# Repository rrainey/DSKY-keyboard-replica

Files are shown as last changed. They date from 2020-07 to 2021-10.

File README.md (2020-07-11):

# DSKY Keyboard Replica

## *This project is a work in progress -- reuse at your own risk*

This is a scale functional replica of the keyboard for the Apollo Guidance Computer. It is implemented
using modern components. The hardware in this project is
designed to be part of a larger replica of the Display and Keyboard (DSKY) module of the AGC.

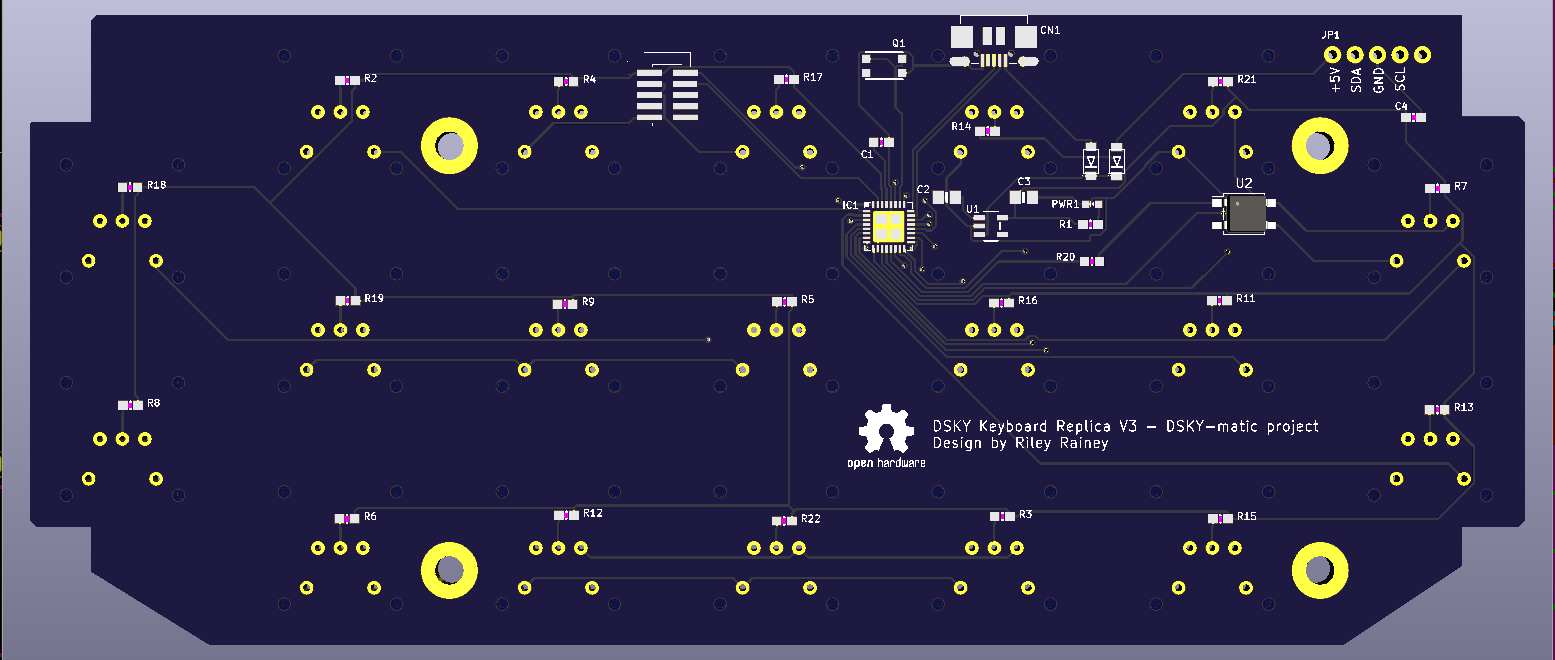
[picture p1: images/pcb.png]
See through view


This keyboard is capable of communicating to a controlling computer (a Raspberry Pi 3 or 4 in my case) via either
a USB or I2C communications interface. The board is controlled by a ATSAMD21 processor. The LP11OA1TBSRG key switches include
green backlighting LEDs, which are controlled by the ATSAMD processor.

This project is composed of these component subfolders:

* pcb - KiCad project for the controller PCB design

* firmware - circuitpython board definition and python-based test and controller firmware

* hardware - 3D-printable frame components designed using Fusion 360. STEP and Fusion source files available. Hardware models used in thie replica were derived from models found in the [AGC Mechanical CAD project](https://github.com/rrainey/agc-mechanical-cad).

## Interfaces

* USB 2.0 Micro-B port
* I2C connection via header pins
* J-LINK-compatible JTAG debugging interface (10-pin header)

## Power Requirements

* +5VDC @ 400ma from either the Micro-B USB connector or a separate +5V header pin

## Credits and Related Projects

This project is inspired by work by Ben Krasnow creating a DSKY Electroluminescent Panel replica. You'll
find information about that project in [this Applied Science video](https://www.youtube.com/watch?v=Z2o_Sp2-aBo) by Ben. Like Ben's E/L display, this project is driven by an AT SAMD21 microcontroller chip; the same chip is used in the multiple Adafruit microcontroller boards, including the Adafruit Trinket M0.

## DSKY Keyboard Replica License

Creative Commons Attribution/Share-Alike, all text above must be included in any redistribution. See license.txt for additional details.

## Adafruit Trinket M0 License

This project includes hardware design elements from the Adafruit [Trinket M0 PCB project](https://github.com/adafruit/Adafruit-Trinket-M0-PCB). Adafruit invests time and resources providing this open source design, please support Adafruit and open-source hardware by purchasing products from [Adafruit](https://www.adafruit.com)!

The Trinket M0 was designed by Limor Fried/Ladyada for Adafruit Industries.

Creative Commons Attribution/Share-Alike, all text above must be included in any redistribution. See license.txt for additional details.

## My Background

My name is Riley Rainey. I'm a software developer by profession. I spent a number of years building aerospace simulations as my day job.

## Getting Support

There's no official support available, but you can [leave comments or create an issue](https://github.com/rrainey/DSKY-keyboard-replica/issues) in this GitHub project.

  
This work is licensed under a [Creative Commons Attribution-ShareAlike 4.0 International License](http://creativecommons.org/licenses/by-sa/4.0/).

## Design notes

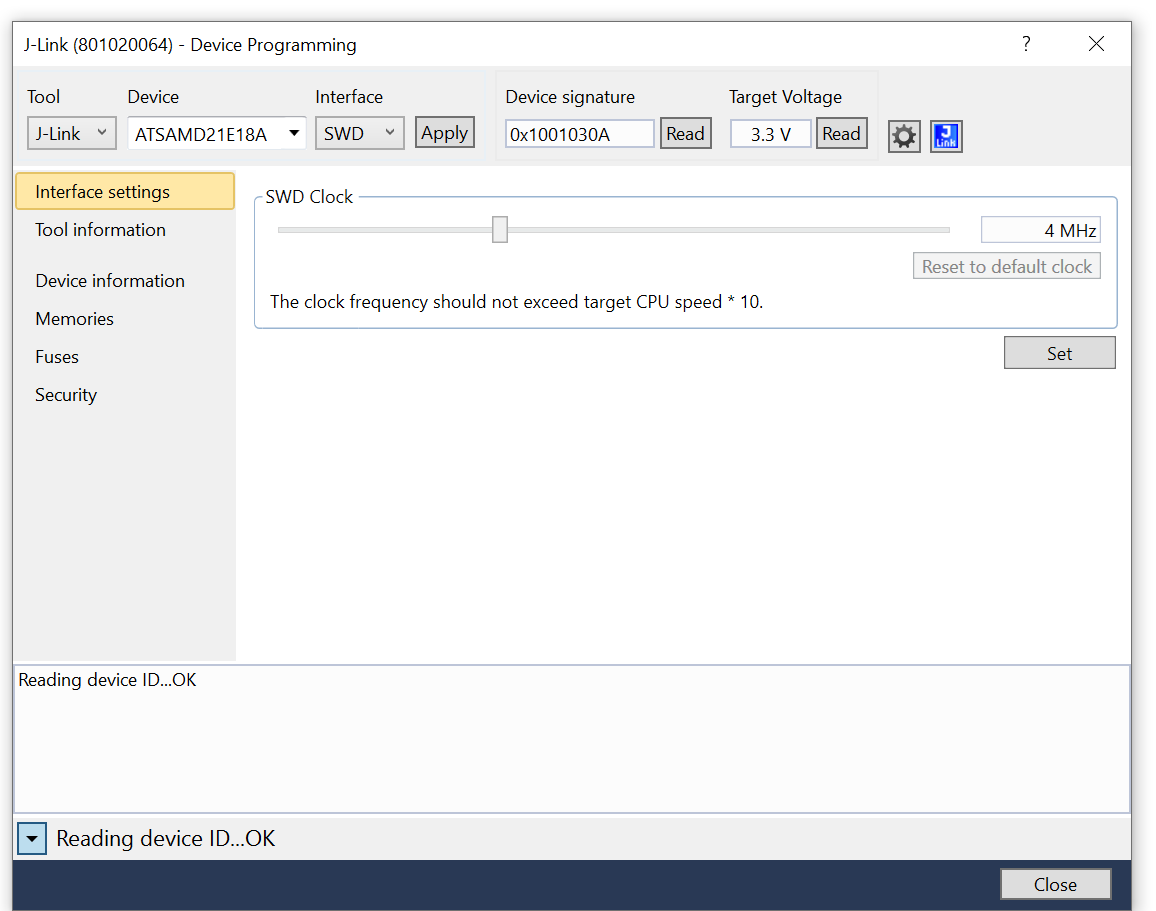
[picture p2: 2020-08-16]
images/keyboard-prog-01.PNG

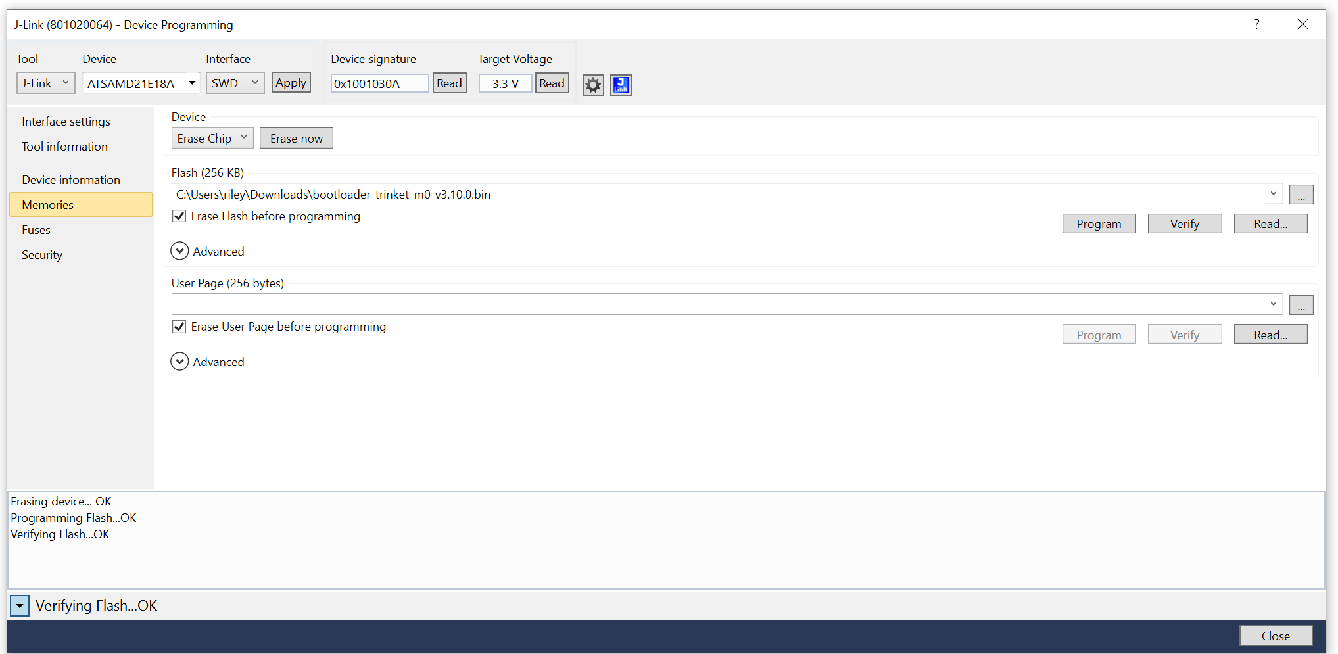
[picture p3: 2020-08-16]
images/keyboard-prog-02.PNG

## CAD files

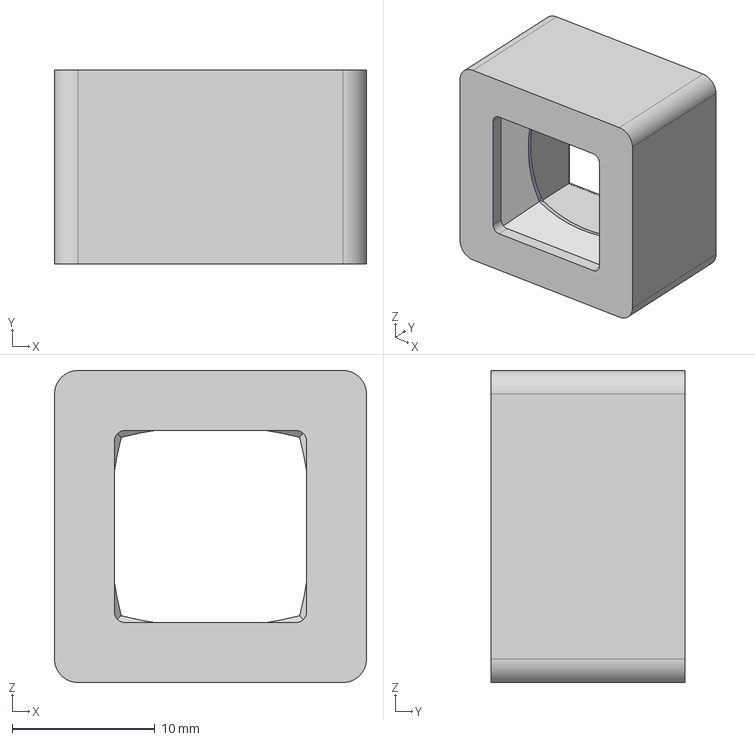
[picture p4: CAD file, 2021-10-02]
hardware/Keycap-base.step
21.8 x 13.6 x 21.8 mm

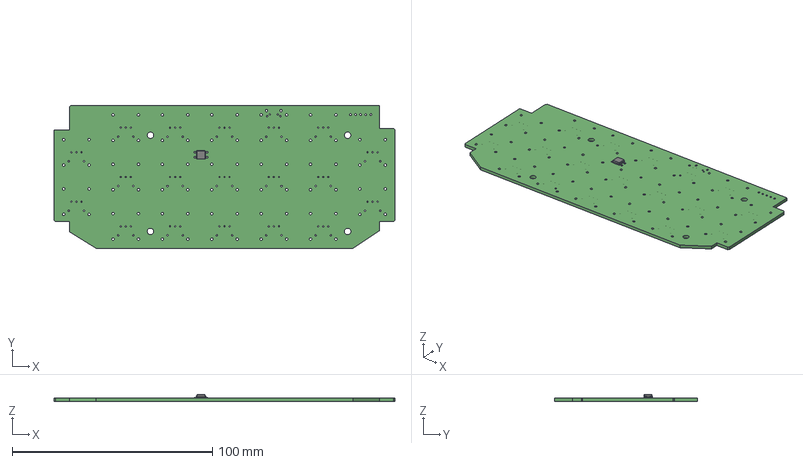
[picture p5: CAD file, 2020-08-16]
pcb/DSKY_keyboard.step
170.2 x 71.1 x 3.25 mm

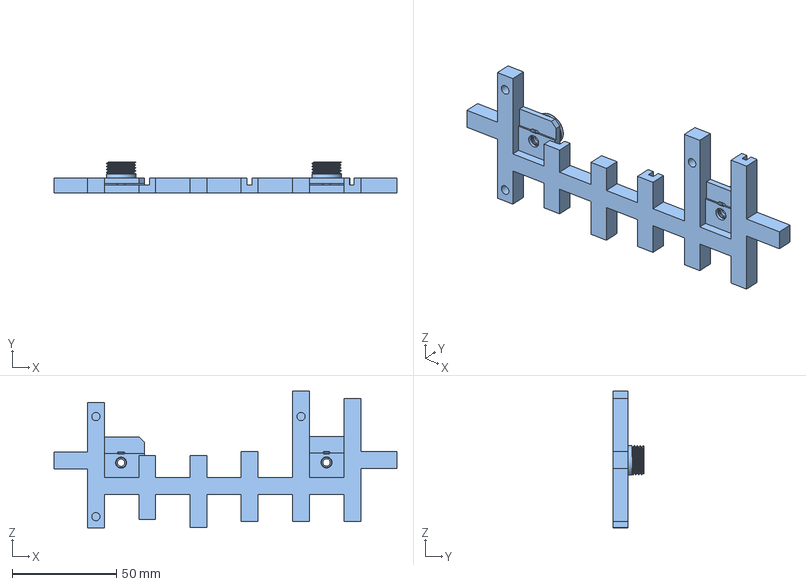
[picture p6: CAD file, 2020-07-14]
hardware/Keyboard PCB Frame.step
164.5 x 14.7 x 65.6 mm

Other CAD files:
hardware/Keyboard PCB Frame.stl
hardware/Keycap-base.stl

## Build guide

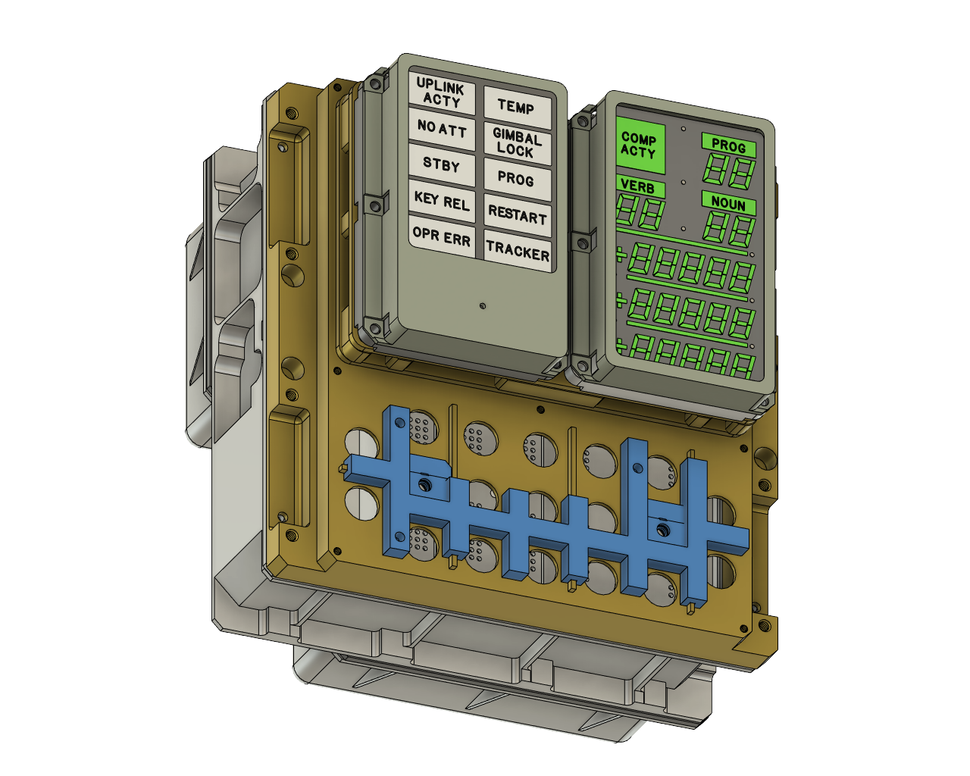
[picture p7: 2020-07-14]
images/ASSEMBLED-PCB-FRAME-02.png

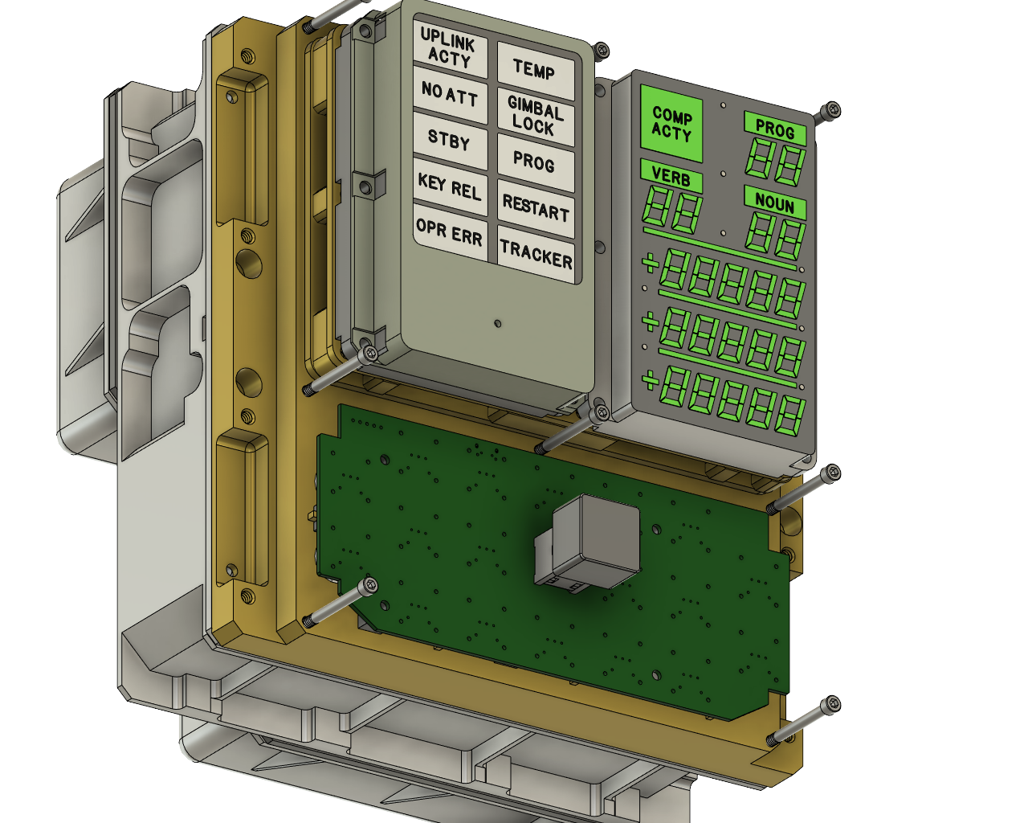
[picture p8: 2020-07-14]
images/ASSEMBLED-PCB-01.png

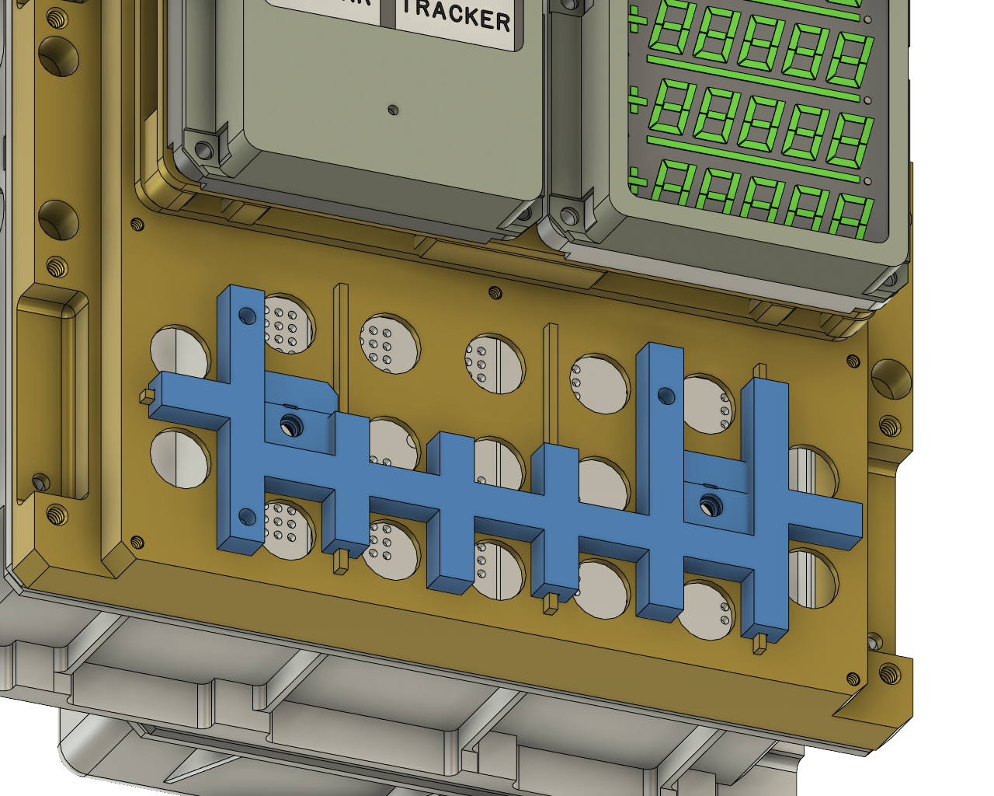
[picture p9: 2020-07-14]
images/ASSEMBLED=PCB-FRAME-01.png

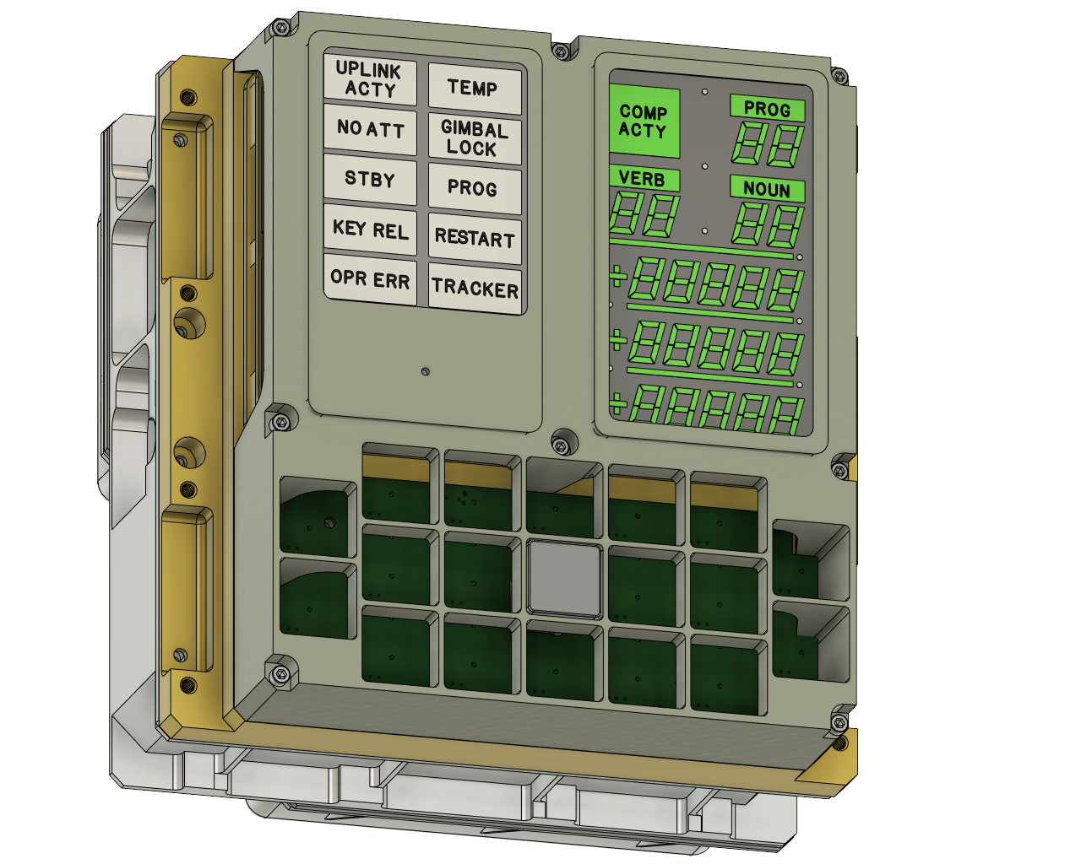
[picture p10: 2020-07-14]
images/ASSEMBLED-PCB-02.png

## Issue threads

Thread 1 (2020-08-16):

PA18 connected to two buttons

rrainey, 2020-08-16:
PA18 is connected to both the (2) and (CLR) buttons.

rrainey, 2020-08-16:
V3 PCB addresses this issue.

Closed 2020-08-16.

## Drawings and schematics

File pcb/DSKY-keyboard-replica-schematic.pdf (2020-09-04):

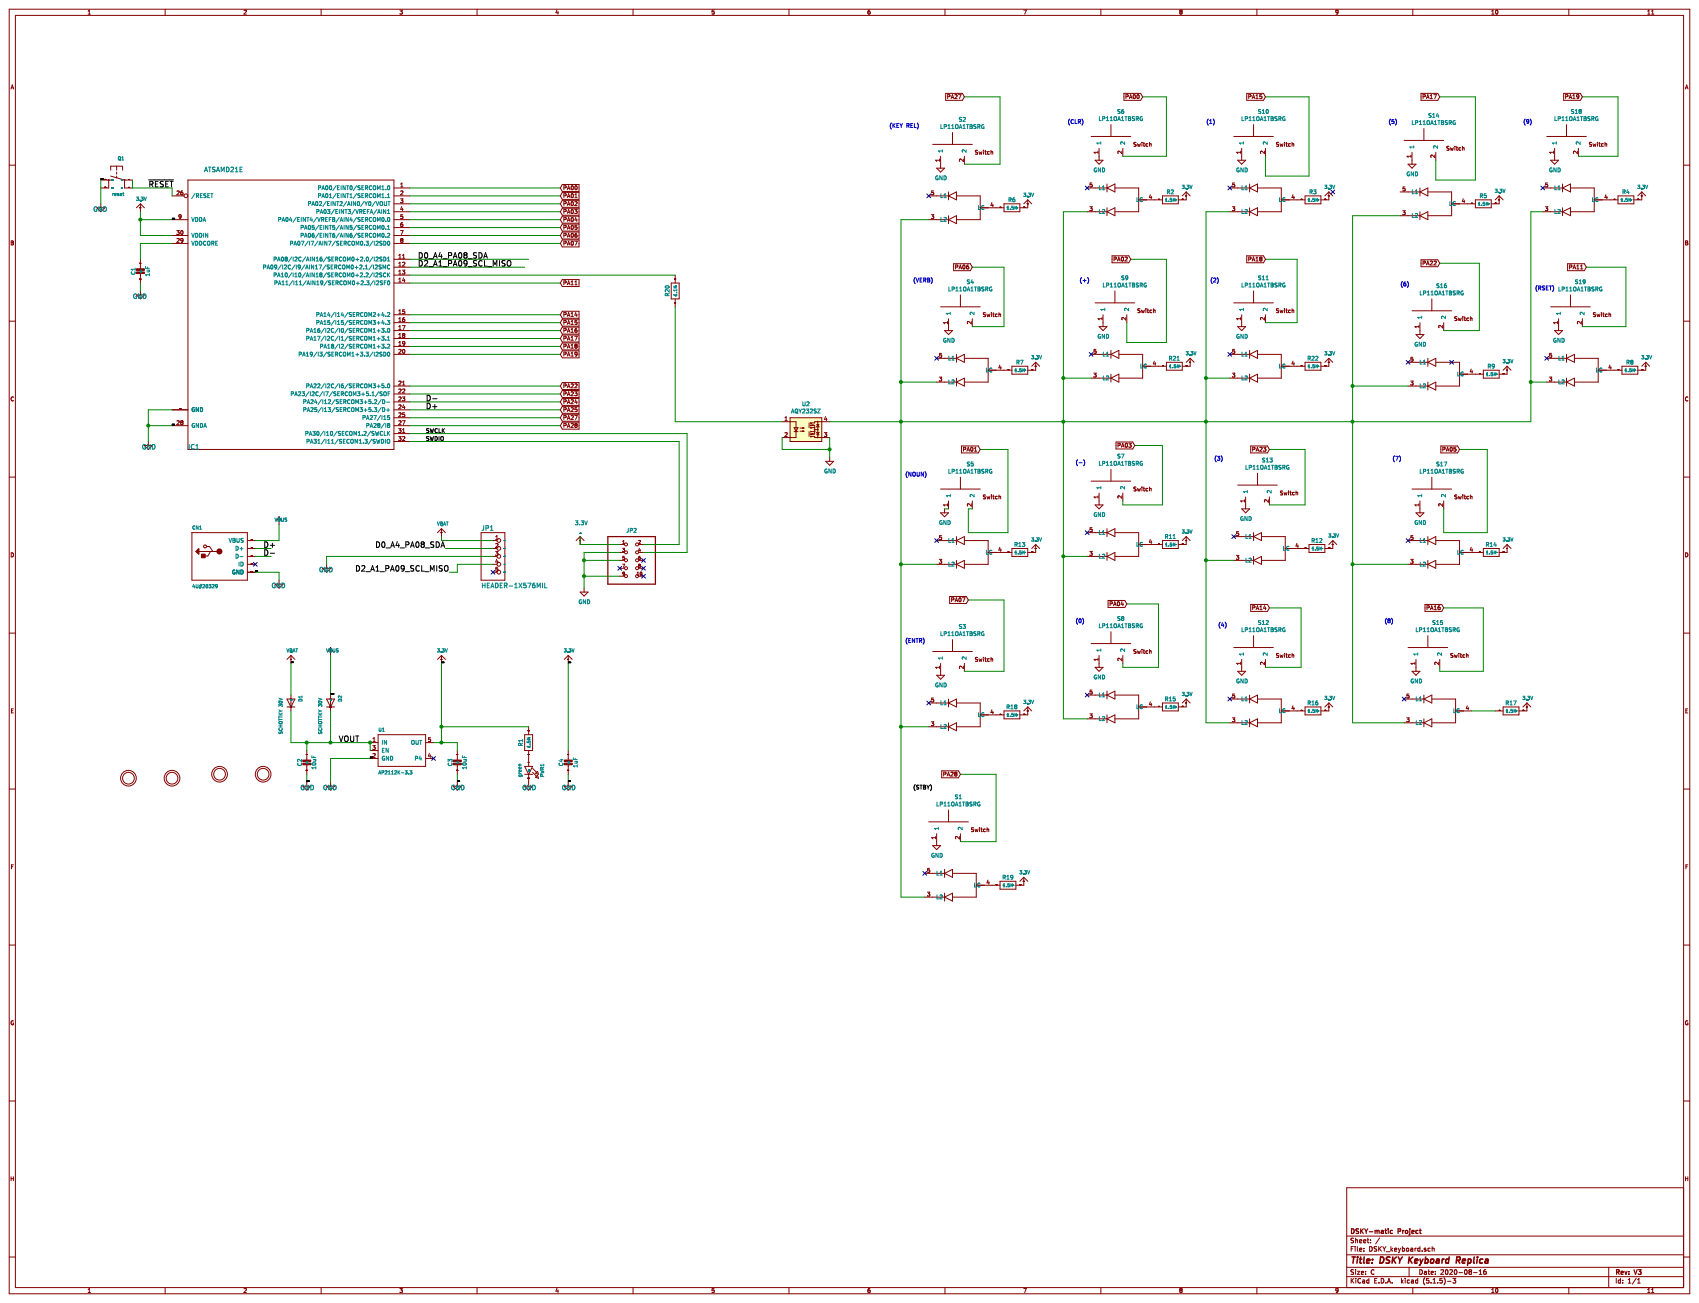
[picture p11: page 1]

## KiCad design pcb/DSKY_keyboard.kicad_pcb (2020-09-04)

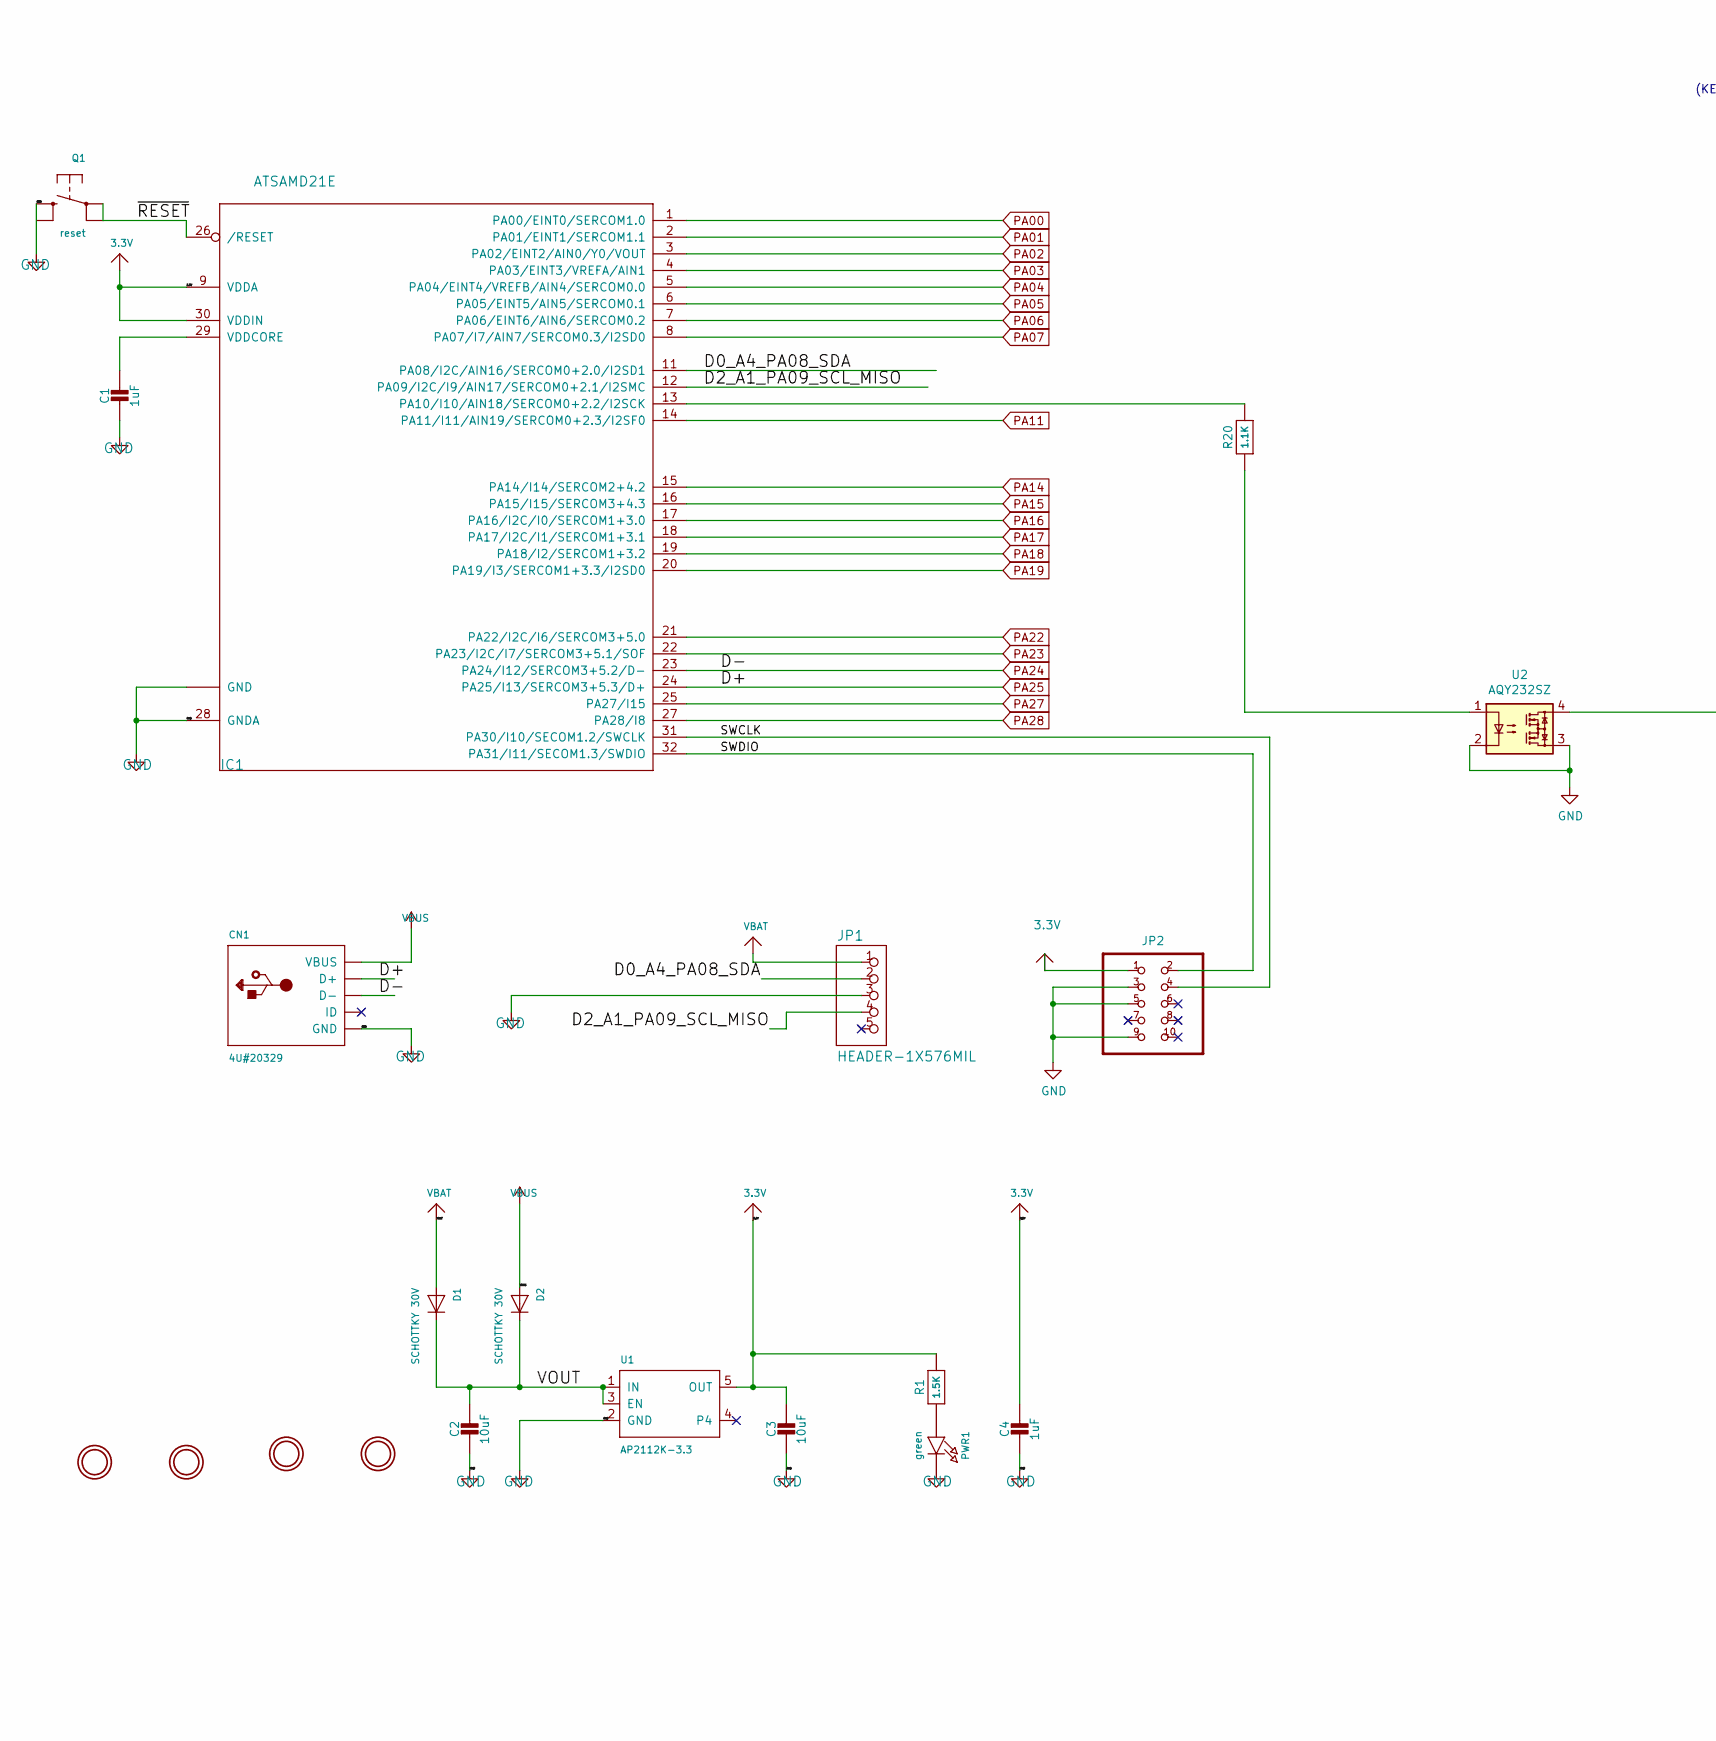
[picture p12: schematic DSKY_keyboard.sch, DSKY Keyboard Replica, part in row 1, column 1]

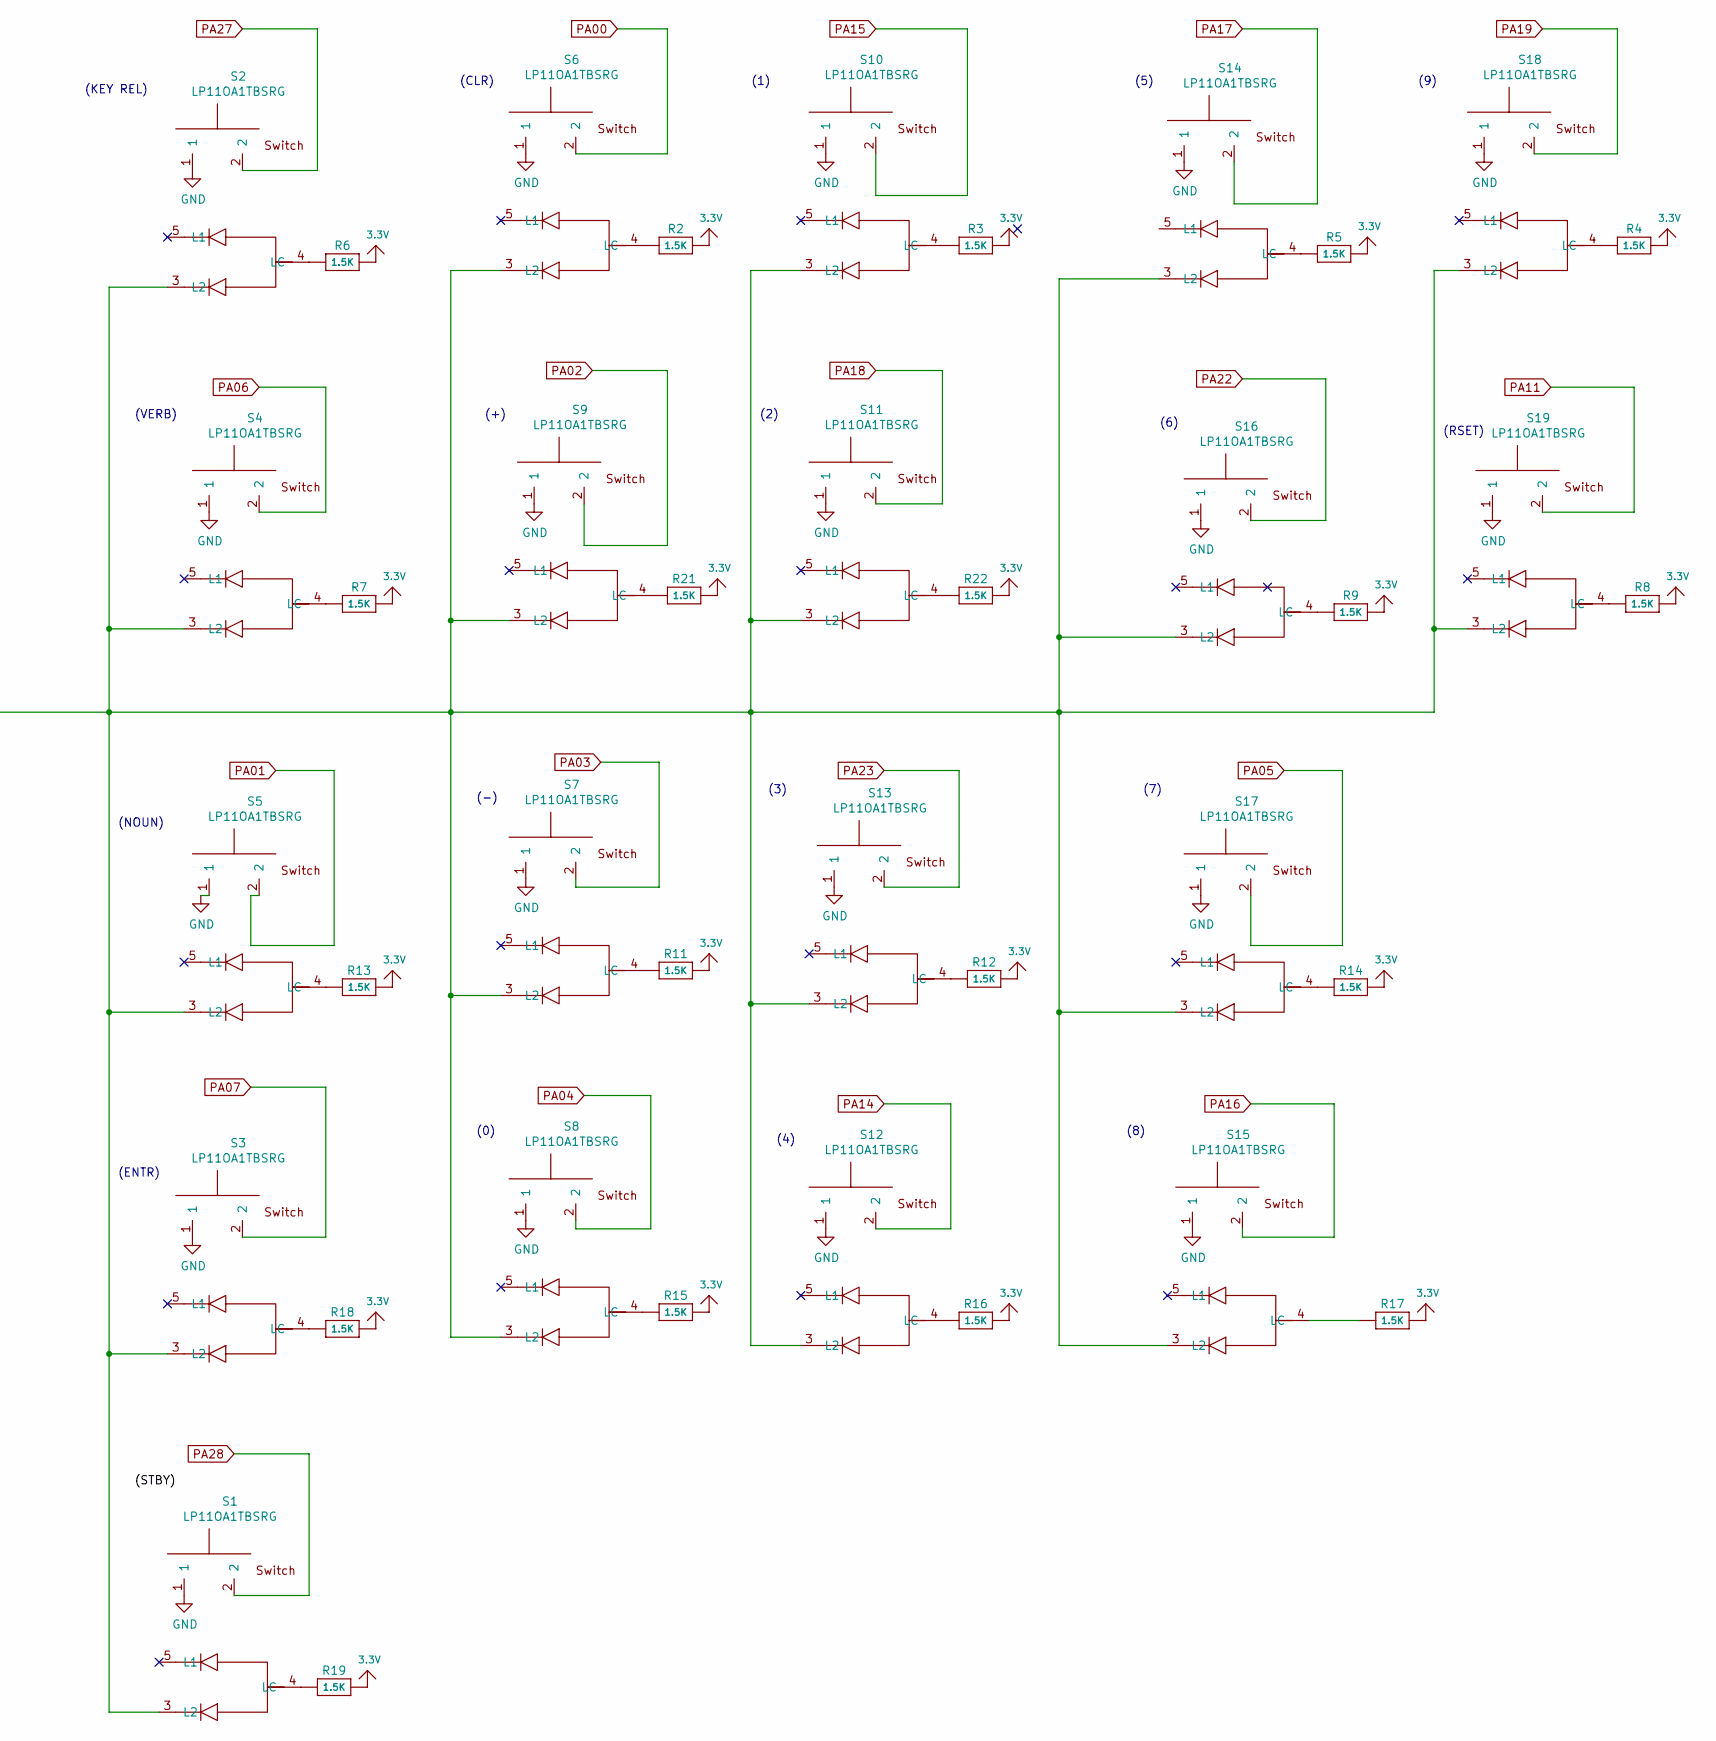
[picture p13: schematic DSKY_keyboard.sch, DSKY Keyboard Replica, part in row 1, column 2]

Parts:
C1, C4: 1uF; 0603-NO
C2, C3: 10uF; 0805-NO
CN1: 4U#20329; 4UCONN_20329_V2
D1, D2: SCHOTTKY 30V; SOD-123FL
IC1: ATSAMD21E; QFN32_5MM
J1, J2, J6, J8: MOUNTINGHOLE3.0; MountingHole_3.2mm_M3_Pad
JP1: HEADER-1X576MIL; 1X05_ROUND_76
JP2: 3221-10-0300-00-TR
PWR1: green; CHIPLED_0603_NOOUTLINE
Q1: reset; BTN_KMR2_4.6X2.8
R1, R2, R3, R4, R5, R6, R7, R8, R9, R11, R12, R13, R14, R15, R16, R17, R18, R19, R21, R22: 1.5K; 0603-NO
R20: 1.1K; 0603-NO
S1, S2, S3, S4, S5, S6, S7, S8, S9, S10, S11, S12, S13, S14, S15, S16, S17, S18, S19: LP11OA1TBSRG
U1: AP2112K-3.3; SOT23-5
U2: AQY232SZ; SO-4_4.4x4.3mm_P2.54mm

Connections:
3.3V: C3.1, C4.1, IC1.9 (VDDA), IC1.30 (VDDIN), JP2.1, R1.2, R2.2, R3.2, R4.2, R5.2, R6.2, R7.2, R8.2, R9.2, R11.2, R12.2, R13.2, R14.2, R15.2, R16.2, R17.2, R18.2, R19.2, R21.2, R22.2, U1.5 (OUT)
/D0_A4_PA08_SDA: IC1.11 (PA08/I2C/AIN16/SERCOM0+2.0/I2SD1), JP1.2
/D2_A1_PA09_SCL_MISO: IC1.12 (PA09/I2C/I9/AIN17/SERCOM0+2.1/I2SMC), JP1.4
/SWCLK: IC1.31 (PA30/I10/SECOM1.2/SWCLK), JP2.4
/SWDIO: IC1.32 (PA31/I11/SECOM1.3/SWDIO), JP2.2
/VOUT: C2.1, D1.C, D2.C, U1.1 (IN), U1.3 (EN)
/~RESET: IC1.26 (/RESET), Q1.A, Q1.A' (P1)
GND: C1.2, C2.2, C3.2, C4.2, CN1.GND, CN1.SPRT@2 (GND), IC1.10 (GND), IC1.28 (GNDA), IC1.33 (GND), JP1.3, JP2.3, JP2.5, JP2.9, PWR1.C, Q1.B (S), S1.1, S2.1, S3.1, S4.1, S5.1, S6.1, S7.1, S8.1, S9.1, S10.1, S11.1, S12.1, S13.1, S14.1, S15.1, S16.1, S17.1, S18.1, S19.1, U1.2 (GND), U2.2, U2.3
unnamed: C1.1, IC1.29 (VDDCORE)
unnamed: IC1.13 (PA10/I10/AIN18/SERCOM0+2.2/I2SCK), R20.2
unnamed: PWR1.A, R1.1
unnamed: R2.1, S6.4 (LC)
unnamed: R3.1, S10.4 (LC)
unnamed: R4.1, S18.4 (LC)
unnamed: R5.1, S14.4 (LC)
unnamed: R6.1, S2.4 (LC)
unnamed: R7.1, S4.4 (LC)
unnamed: R8.1, S19.4 (LC)
unnamed: R9.1, S16.4 (LC)
unnamed: R11.1, S7.4 (LC)
unnamed: R12.1, S13.4 (LC)
unnamed: R13.1, S5.4 (LC)
unnamed: R14.1, S17.4 (LC)
unnamed: R15.1, S8.4 (LC)
unnamed: R16.1, S12.4 (LC)
unnamed: R17.1, S15.4 (LC)
unnamed: R18.1, S3.4 (LC)
unnamed: R19.1, S1.4 (LC)
unnamed: R20.1, U2.1
unnamed: R21.1, S9.4 (LC)
unnamed: R22.1, S11.4 (LC)
unnamed: S1.3 (L2), S2.3 (L2), S3.3 (L2), S4.3 (L2), S5.3 (L2), S6.3 (L2), S7.3 (L2), S8.3 (L2), S9.3 (L2), S10.3 (L2), S11.3 (L2), S12.3 (L2), S13.3 (L2), S14.3 (L2), S15.3 (L2), S16.3 (L2), S17.3 (L2), S18.3 (L2), S19.3 (L2), U2.4
PA00: IC1.1 (PA00/EINT0/SERCOM1.0), S6.2
PA01: IC1.2 (PA01/EINT1/SERCOM1.1), S5.2
PA02: IC1.3 (PA02/EINT2/AIN0/Y0/VOUT), S9.2
PA03: IC1.4 (PA03/EINT3/VREFA/AIN1), S7.2
PA04: IC1.5 (PA04/EINT4/VREFB/AIN4/SERCOM0.0), S8.2
PA05: IC1.6 (PA05/EINT5/AIN5/SERCOM0.1), S17.2
PA06: IC1.7 (PA06/EINT6/AIN6/SERCOM0.2), S4.2
PA07: IC1.8 (PA07/I7/AIN7/SERCOM0.3/I2SD0), S3.2
PA11: IC1.14 (PA11/I11/AIN19/SERCOM0+2.3/I2SF0), S19.2
PA14: IC1.15 (PA14/I14/SERCOM2+4.2), S12.2
PA15: IC1.16 (PA15/I15/SERCOM3+4.3), S10.2
PA16: IC1.17 (PA16/I2C/I0/SERCOM1+3.0), S15.2
PA17: IC1.18 (PA17/I2C/I1/SERCOM1+3.1), S14.2
PA18: IC1.19 (PA18/I2/SERCOM1+3.2), S11.2
PA19: IC1.20 (PA19/I3/SERCOM1+3.3/I2SD0), S18.2
PA22: IC1.21 (PA22/I2C/I6/SERCOM3+5.0), S16.2
PA23: IC1.22 (PA23/I2C/I7/SERCOM3+5.1/SOF), S13.2
PA24: CN1.D-, IC1.23 (PA24/I12/SERCOM3+5.2/D-)
PA25: CN1.D+, IC1.24 (PA25/I13/SERCOM3+5.3/D+)
PA27: IC1.25 (PA27/I15), S2.2
PA28: IC1.27 (PA28/I8), S1.2
VBAT: D1.A, JP1.1
VBUS: CN1.VBUS, D2.A

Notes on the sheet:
(KEY REL)
(VERB)
(NOUN)
(ENTR)
(CLR)
(+)
(-)
(1)
(4)
(5)
(6)
(8)
(9)
(RSET)
(2)
(7)
(0)
(3)

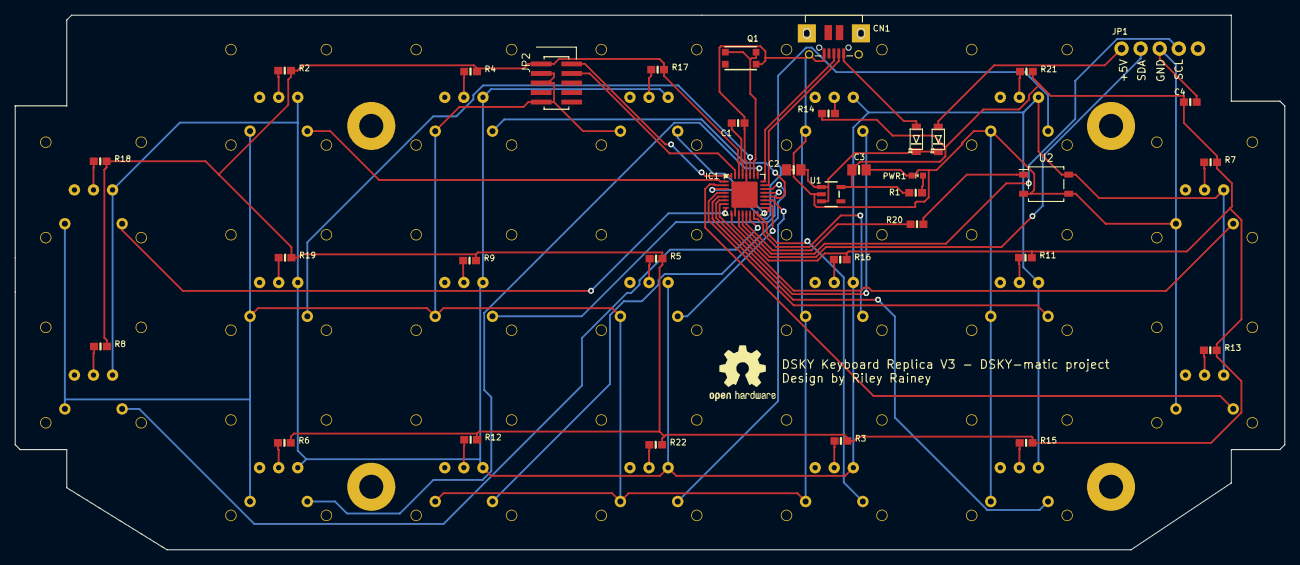
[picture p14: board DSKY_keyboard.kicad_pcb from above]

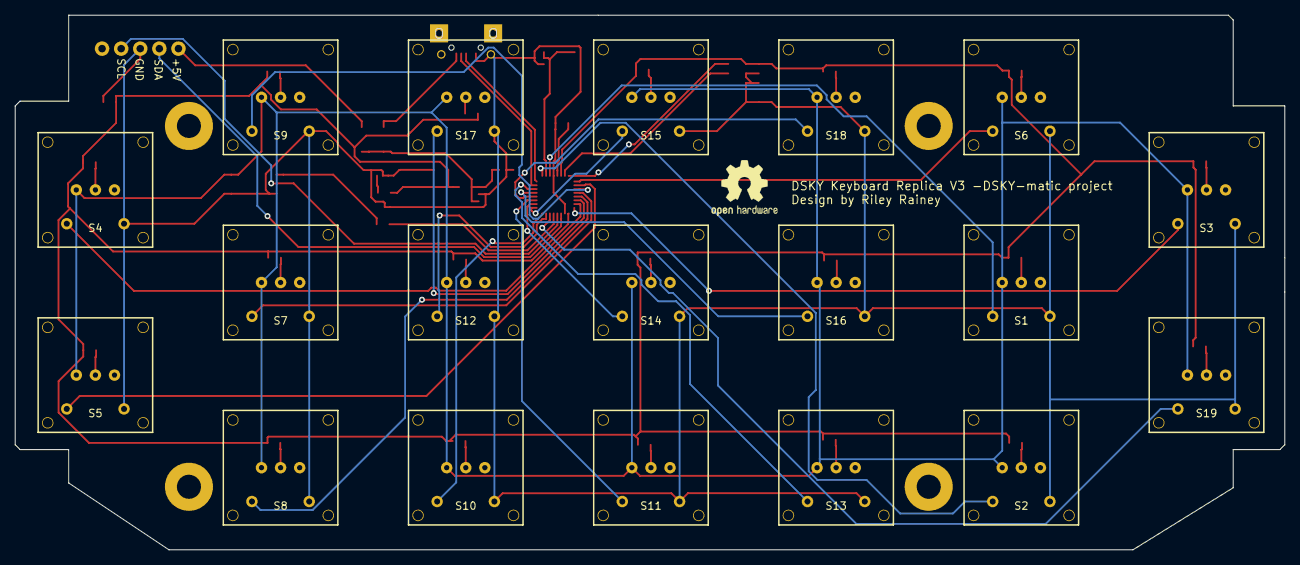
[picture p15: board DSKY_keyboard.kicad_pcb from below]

Board: 2 copper layers, 168.9 x 71.1 mm, 59 parts (19 on the bottom side), 55 nets.

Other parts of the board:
REF1: OSHW-Logo2_9.8x8mm_SilkScreen

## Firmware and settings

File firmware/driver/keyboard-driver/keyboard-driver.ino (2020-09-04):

/*
Copyright (c) 2020, Riley Rainey

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
THE SOFTWARE IS PROVIDED "AS IS", WITHOUT WARRANTY OF ANY KIND, EXPRESS OR
IMPLIED, INCLUDING BUT NOT LIMITED TO THE WARRANTIES OF MERCHANTABILITY,
FITNESS FOR A PARTICULAR PURPOSE AND NONINFRINGEMENT. IN NO EVENT SHALL THE
AUTHORS OR COPYRIGHT HOLDERS BE LIABLE FOR ANY CLAIM, DAMAGES OR OTHER
LIABILITY, WHETHER IN AN ACTION OF CONTRACT, TORT OR OTHERWISE, ARISING FROM,
OUT OF OR IN CONNECTION WITH THE SOFTWARE OR THE USE OR OTHER DEALINGS IN THE
SOFTWARE.
*/
#include <Arduino.h>
#include <Wire.h>

#define DRIVER_VERSION 1
#define I2C_ADDRESS    0x39

/*
 * This is the driver for the DSKY-matic keyboard.  It provides software debouncing of the
 * keyboard pushbuttons and sends key press/release events via the I2C interface 
 * when polled on the I2C interface
 * 
 * This driver must be built using the "dskymatic_m0" board definition. See README.md for 
 * Arduino IDE setup instructions.  The dskymatic_m0 definition is a superset of the Adafruit
 * Trinket M0 definition so, if you simply want to see it build, you may select that board.  There will
 * be gaps, however in its ability to fully drive the DSKY-matic keyboard PCB.
 */

#define PIN_BACKLIGHT 7
#define PIN_RED_LED  13

// consult variant.cpp for the dskymatic_m0 board definition
// to see how digital pins were added

#define PA_PIN(x) (23+(x))

/*
 * Valid for V2 Board
 * /
/*
#define PIN_S1_STBY     PA_PIN(28)
#define PIN_S2_KEY_REL  PA_PIN(27)
#define PIN_S3_ENTR     PA_PIN(7)
#define PIN_S4_VERB     PA_PIN(6)
#define PIN_S5_NOUN     PA_PIN(1)
#define PIN_S6_CLR      PA_PIN(18)
#define PIN_S7_MINUS    PA_PIN(3)
#define PIN_S8_0        PA_PIN(4)
#define PIN_S9_PLUS     PA_PIN(2)
#define PIN_S10_1       PA_PIN(15)
#define PIN_S11_2       PA_PIN(18)
#define PIN_S12_4       PA_PIN(14)
#define PIN_S13_3       PA_PIN(23)
#define PIN_S14_5       PA_PIN(17)
#define PIN_S15_8       PA_PIN(16)
#define PIN_S16_6       PA_PIN(22)
#define PIN_S17_7       PA_PIN(5)
#define PIN_S18_9       PA_PIN(19)
#define PIN_S19_RSET    PA_PIN(11)
*/

#define SMAP_IGNORE 255
#define SMAP_SIZE 19
#define SMAP_USED 19

//#define SMAP_SIZE 2
//#define SMAP_USED 8

/*
 * VERB(4,18) NOUN(8) ENTR (3) STBY (9(\)
 */

// (CLR) currently must be ignored in V2 board
const uint8_t s_map[SMAP_SIZE] = {
  //PA_PIN(28),
  SMAP_IGNORE,
  PA_PIN(27),
  PA_PIN(7),
  PA_PIN(6),
  PA_PIN(1),
  SMAP_IGNORE,
  PA_PIN(3),
  PA_PIN(4),
  PA_PIN(2),
  PA_PIN(15),
  PA_PIN(18),
  PA_PIN(23),
  PA_PIN(14),
  PA_PIN(17),
  PA_PIN(22),
  PA_PIN(5),
  PA_PIN(16),
  PA_PIN(19),
  PA_PIN(11)
};


enum KeyState {
  NORMAL = 0,
  PRESSED = 1
};

KeyState g_keystate[SMAP_SIZE];

uint16_t g_bounce[SMAP_SIZE];

struct _key_event {
  unsigned long time;
  uint8_t       key;
  uint8_t       new_state;
};

/*
 * All key state changes are logged in a queue.
 * Items are removed from the queue by being 
 * polled via the I2C interface
 */
#define QUEUE_MAX 16

unsigned int qhead = 0;
unsigned int qtail = 0;
unsigned int qcount = 0;
struct _key_event event_queue[QUEUE_MAX];

/*
 * Current setting corrspond to a 28ms debounce check
 */
#define CHECK_INTERVAL_MS    4
//#define DEBOUNCE_IGNORE_MASK 0xe000
#define DEBOUNCE_IGNORE_MASK 0xff80
#define DEBOUNCE_TRIGGER     0xffff

/*
 * Push a key event to the tail of the queue; no action if 
 * the queue is full
 */
void pushEvent(unsigned long time, uint8_t key, KeyState new_state) {
  // overflowing? ignore this push request
  if (qcount < QUEUE_MAX) {
    struct _key_event *p = &event_queue[qtail];
  
    p->time = time;
    p->key = key;
    p->new_state = new_state;
    qtail = (qtail + 1) % QUEUE_MAX;
    ++qcount;
  }
}

/*
 * Pop next key event off the head of the queue or return NULL if
 * none present.
 */
struct _key_event *popEvent() {
  struct _key_event *p = NULL;
  if (qtail != qhead ) {
    p = &event_queue[qhead];
    qhead = (qhead+1) % QUEUE_MAX;
    --qcount;
  }
  return p;
}

void stateCheck(int key)
{
  int pin = s_map[key];
  
  if (pin == SMAP_IGNORE) {
    return;
  }

  /*
   * g_bounce is basically a string of boolean poll result history for a given key. 
   * This allows for a window of time for a key to settle into a new state.
   * Polling is currently performed on a 4ms interval and 13 bit history is maintained, so
   * the current configuration allows for a 4x13 = 52ms settle time.
   */
  
  if (g_keystate[key] == NORMAL) {
    g_bounce[key] = (g_bounce[key] << 1) | ((digitalRead(pin) == LOW) ? 1 : 0);

    if (g_bounce[key] == DEBOUNCE_TRIGGER) {
      g_keystate[key] = PRESSED;
      pushEvent(millis(), key+1, PRESSED);
      g_bounce[key] = DEBOUNCE_IGNORE_MASK;
    }
  }
  else {
    g_bounce[key] = (g_bounce[key] << 1) | ((digitalRead(pin) == HIGH) ? 1 : 0);

    if (g_bounce[key] == DEBOUNCE_TRIGGER) {
      g_keystate[key] = NORMAL;
      pushEvent(millis(), key+1, NORMAL);
      g_bounce[key] = DEBOUNCE_IGNORE_MASK;
    }
  }
}

void requestEvent() {
  struct _key_event *p = popEvent();
  unsigned char buffer[6];

  if (p == NULL) {
    // buffer empty; return current millis() time
    unsigned long i = millis();
    buffer[0] = (i >> 24) & 0xff;
    buffer[1] = (i >> 16) & 0xff;
    buffer[2] = (i >> 8) & 0xff;
    buffer[3] = i & 0xff;
    buffer[4] = 0;
    buffer[5] = 0xff;
  }
  else {
    buffer[0] = (p->time >> 24) & 0xff;
    buffer[1] = (p->time >> 16) & 0xff;
    buffer[2] = (p->time >> 8) & 0xff;
    buffer[3] = p->time & 0xff;
    buffer[4] = p->key;
    buffer[5] = p->new_state;
  }
  Wire.write(buffer, sizeof(buffer));
}

void bounceInit() {
  for(int i=0; i<SMAP_USED; ++i) {
    if (s_map[i] != SMAP_IGNORE) {
      pinMode(s_map[i], INPUT_PULLUP);
      g_keystate[i] = NORMAL;
      g_bounce[i] = DEBOUNCE_IGNORE_MASK;
    }
  }
}

void setup() 
{
  pinMode(PIN_BACKLIGHT, OUTPUT);
  digitalWrite(PIN_BACKLIGHT, HIGH);

  pinMode(PIN_RED_LED, OUTPUT);
  digitalWrite(PIN_RED_LED, HIGH);

  bounceInit();
  /* 
   *  Connect to I2C Bus
   */
  Wire.begin( I2C_ADDRESS );
  Wire.onRequest( requestEvent );
}

void checkKeyboard()
{
  for(int i=0; i<SMAP_USED; ++i) {
    stateCheck(i);
  }
}

int count = 250;
bool state = true;

void loop() {

  // Health indicator; blinks the keyboard backlighting
  if (--count == 0 ) {
    count = 250;
    if (state) {
      digitalWrite(PIN_BACKLIGHT, LOW);
      state = false;
    }
    else {
      digitalWrite(PIN_BACKLIGHT, HIGH);
      state = true;
    }
  }
  checkKeyboard();
  delay ( CHECK_INTERVAL_MS );
}

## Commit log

2020-07-11 Initial PCB import
    [DSKY_keyboard.kicad_pcb, DSKY_keyboard.sch, subsheet.sch]
2020-07-11 Revised the board outline to eliminate two mechanical clearance issues
    [DSKY_keyboard.kicad_pcb]
2020-07-14 Added a few images + the prototype PCB mounting frame
    [DSKY_keyboard.sch, Keyboard PCB Frame.step, Keyboard PCB Frame.stl]
2020-08-16 initial version of driver
2020-08-16 change I2C message to a 6-byte length
2020-08-16 tidy-up millis() interactions
2020-08-16 Issue #1
    Board now has (CLR) on PA00; backlighting always on. V3 board
    [DSKY_keyboard.kicad_pcb, DSKY_keyboard.sch, DSKY_keyboard.step]
2020-08-16 Update J-Link Header PCB Footprint
    [DSKY_keyboard.kicad_pcb, DSKY_keyboard.sch]
2020-08-20 change queue-empty response message to return the current millis() time
2020-08-29 stable mostly functional driver
2020-09-04 V2 Board complete
    V3 updates subsequent to full-up V2 board tests (incl. firmware)
    [DSKY_keyboard.kicad_pcb, DSKY_keyboard.sch]
2020-09-04 Update PCB 3D rendering
2020-09-19 Update for V4 PCB
2021-10-02 Updated keycap
    [Keycap-base.step, Keycap-base.stl]

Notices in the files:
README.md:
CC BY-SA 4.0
